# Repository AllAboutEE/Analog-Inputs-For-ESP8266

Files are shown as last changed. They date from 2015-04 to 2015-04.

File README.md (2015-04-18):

# MCP3021 Array Breakout Board
A breakout board for four (4) I2C 10-bit analog to digital (A/D) converters. 

## Where to Buy

## What is it?
A board with four analog to digital (A/D) converters that your ESP8266 can interface with it using I2C.

## Why did you make it?
The ESP8266 is great module, but it lacks some functionality that it's often necessary to use another microcontroller to accomplish what you want. One of the features that it lacks are A/D converters (it only has one and it's hard to access if you have the ESP-01 version).

## Hardware

### Technical Details

- 4 Microchip MCP3021 A/D converters
- I2C interface
- 10-bit resolution
- Single supply specified operation: 2.7V to 5.5V

[MCP3021 A/D converter datasheet](http://ww1.microchip.com/downloads/en/DeviceDoc/21805B.pdf)

## Software

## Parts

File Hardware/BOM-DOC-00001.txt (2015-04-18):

Partlist exported from C:/Users/Miguel/Documents/eagle/MCP3021A-Array-Breakout/Hardware/DOC-00001.sch at 3/19/2015 11:53:24 AM

Part Value            Device         Package     Description                MPN              PRICE STORE              
C1   0.1uF            C-USC0805K     C0805K      CAPACITOR, American symbol VJ0805Y104MXXAC  0.06  mouser.com         
JP1  v                PINHD-1X8      1X08        PIN HEADER                 825433-8         0.84  mouser.com         
R1   4.7k             R-US_R0805     R0805       RESISTOR, American symbol  CRCW08054K70FKEA 0.08  mouser.com         
R2   4.7k             R-US_R0805     R0805       RESISTOR, American symbol  CRCW08054K70FKEA 0.08  mouser.com         
U$1  MCP3021A0T-E/OT  MCP3021XX-X/OT SOT-23-5_MC                            MCP3021A0T-E/OT  1.07  microchipdirect.com
U$2  MCP3021A1T-E/OT  MCP3021XX-X/OT SOT-23-5_MC                            MCP3021A1T-E/OT  1.07  microchipdirect.com
U$3  MCP3021A2T-E/OT  MCP3021XX-X/OT SOT-23-5_MC                            MCP3021A2T-E/OT  1.07  microchipdirect.com
U$4  MCP3021A3T-E/OT  MCP3021XX-X/OT SOT-23-5_MC                            MCP3021A3T-E/OT  1.07  microchipdirect.com

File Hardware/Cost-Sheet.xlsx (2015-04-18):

Order Name | Cost (USD) | Comments
PCB | 2.5 | Free shipping
Converters | 46.32 | 40 sensors. Free shipping until march 30 coupon saved ~$6.00
R,C,H | 16.18 | Resistors, Caps, 1x8 Headers. Shipping was 4.99
Total | 65

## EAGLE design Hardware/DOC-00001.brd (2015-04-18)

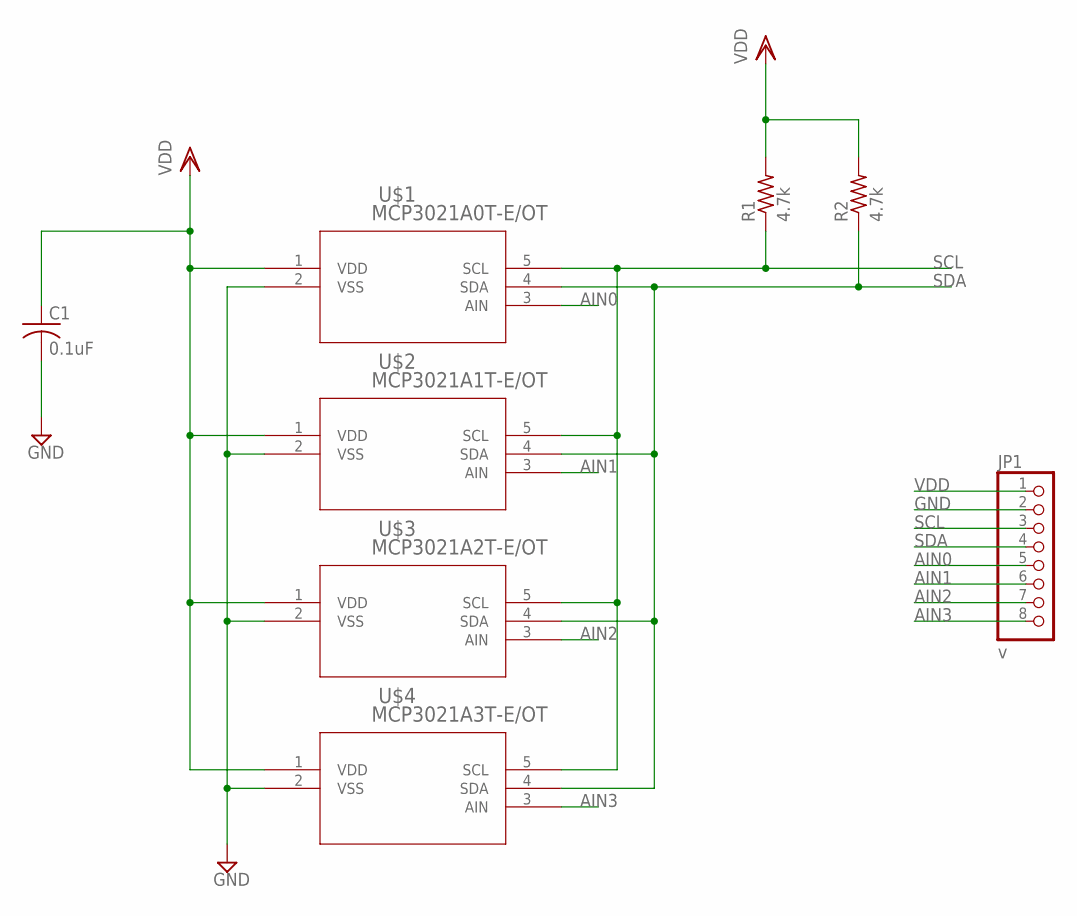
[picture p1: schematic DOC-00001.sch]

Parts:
C1: 0.1uF; C0805K; MPN VJ0805Y104MXXAC
JP1: v; 1X08; MPN 825433-8
R1, R2: 4.7k; R0805; MPN CRCW08054K70FKEA
U$1: MCP3021A0T-E/OT; SOT-23-5_MC; MPN MCP3021A0T-E/OT
U$2: MCP3021A1T-E/OT; SOT-23-5_MC; MPN MCP3021A1T-E/OT
U$3: MCP3021A2T-E/OT; SOT-23-5_MC; MPN MCP3021A2T-E/OT
U$4: MCP3021A3T-E/OT; SOT-23-5_MC; MPN MCP3021A3T-E/OT

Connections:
AIN0: JP1.5, U$1.3 (AIN)
AIN1: JP1.6, U$2.3 (AIN)
AIN2: JP1.7, U$3.3 (AIN)
AIN3: JP1.8, U$4.3 (AIN)
GND: C1.2, JP1.2, U$1.2 (VSS), U$2.2 (VSS), U$3.2 (VSS), U$4.2 (VSS)
SCL: JP1.3, R1.1, U$1.5 (SCL), U$2.5 (SCL), U$3.5 (SCL), U$4.5 (SCL)
SDA: JP1.4, R2.1, U$1.4 (SDA), U$2.4 (SDA), U$3.4 (SDA), U$4.4 (SDA)
VDD: C1.1, JP1.1, R1.2, R2.2, U$1.1 (VDD), U$2.1 (VDD), U$3.1 (VDD), U$4.1 (VDD)

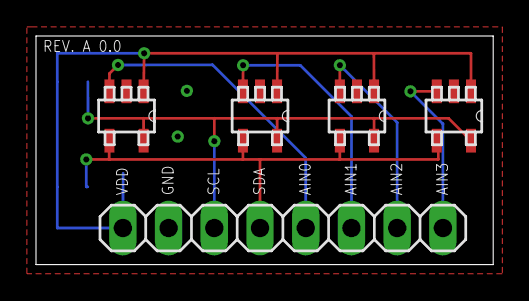
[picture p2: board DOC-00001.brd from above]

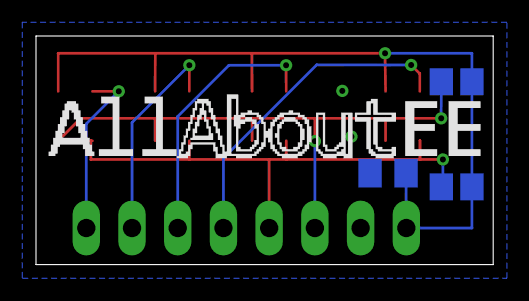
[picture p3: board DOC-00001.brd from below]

Board: 2 copper layers, 25.4 x 12.7 mm, 8 parts (3 on the bottom side), 8 nets.

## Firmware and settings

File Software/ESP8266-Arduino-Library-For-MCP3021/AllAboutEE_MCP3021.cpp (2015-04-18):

#include <AllAboutEE_MCP3021.h>

/**
 * @brief Sets the pin and fixed address bits for I2C
 * 
 * @author Carlos (4/12/2015)
 * 
 * @param sda The SDA pin number
 * @param scl The SCL pin number
 */
void AllAboutEE::MCP3021::begin(int sda, int scl)
{
	Wire.pins(sda,scl);
	Wire.begin(MCP3021_I2C_ADDRESS);
}

/**
 * @brief Gives a conversion's result as a digital value between
 *        0 and 1023
 * 
 * @author Carlos (4/12/2015)
 * 
 * @param deviceId The last three bits in the device's I2C 
 *                 address. This would be the last number in
 *                 device's name e.g. for an MCP3021A5 deviceId
 *                 = 5, for an MCP3021A3 deviceId = 3.
 * 
 * @return uint16_t The 10-bit conversion result, a value from 0
 *         to 1023
 */
uint16_t AllAboutEE::MCP3021::read(int deviceId)
{
    // we'll read the bytes from the I2C bus into this array
    uint8_t data[2];
    data[0] = 0x00;
    data[1] = 0x00;

    // the array is a 10-bit result, the smallest type that can contain it is uint16_t
    uint16_t result = 0x0000;

    // The device's address is binary [1][0][0][1][A0][A1][A2] where [A0][A1][A2] is the device's unique id
    Wire.requestFrom(MCP3021_I2C_ADDRESS|deviceId, 2);

    for(int i =0; Wire.available() > 0;i++)
    {
        data[i] = Wire.read();
    }
    // The converter's 10-bit result is two bytes that looks like this:
    // [0][0][0][0][D9][D8][D7][D6] [D5][D4][D3][D1][D0][x][x]
    // so to put them in one variable ...
    result = (result | data[0]) << 6; // we take the MSB and shift it left 6 times
    data[1] = data[1] >> 2; // we take the LSB and shift it right two times
    result = result | data[1]; // we OR both bytes

    return result;
}

/**
 * @brief Gives a converter's result as an analog value between 
 *        0 and VDD
 * 
 * @author Carlos (4/12/2015)
 * 
 * @param deviceId The last three bits in the device's I2C 
 *                 address. This would be the last number in
 *                 device's name e.g. for an MCP3021A5 deviceId
 *                 = 5, for an MCP3021A3 deviceId = 3.
 *  
 * @param vdd The output of the power supply used to power the 
 *            converter.
 * 
 * @return float The conversion result from 0 to VDD
 */
float AllAboutEE::MCP3021::read(int deviceId, float vdd)
{
	uint16_t result = read(deviceId);
	
	return ((float)result * (vdd / 1023));	
}

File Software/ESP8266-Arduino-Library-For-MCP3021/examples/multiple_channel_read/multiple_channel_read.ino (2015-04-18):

/** 
 *  @details Need more analog pins for your ESP8266? This
 *        example shows how to read and print a digital and
 *        analog value from the MCP3021A0, MCP3021A1, MCP3021A2,
 *        and MCP3021A3 converters.
 *  
 * @link  You can buy an MCP3021 array breakout board from this 
 *        URL: 
 *  
 *  
 * @note Converter datasheet 
 *       http://ww1.microchip.com/downloads/en/DeviceDoc/21805B.pdf
 * 
 */
#include <AllAboutEE_MCP3021.h>
#include <Wire.h>

using namespace AllAboutEE;

MCP3021 mcp3021;


void setup()
{
  mcp3021.begin(0,2);
  Serial.begin(9600);
}

void loop()
{
	Serial.println("New Readings");
		
	for(int i = 0; i < 4; i++) // read analog value from converters MCP3021A0 to MCP3021A3 (that is 4 converters total)
	{
		Serial.print("Channel ");
		Serial.println(i);
		Serial.print("Digital Value: ");
		Serial.println(mcp3021.read(i));

		Serial.print("Analog Value: ");
		Serial.println(mcp3021.read(i,3.3));
		Serial.println();
		delay(500);
	}
	  
}

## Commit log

2015-03-19 First commit. Added schematic and board files.
    [DOC-00001.brd, DOC-00001.sch]
2015-03-19 Routed. Needs ground layers.
    [DOC-00001.brd, DOC-00001.sch]
2015-03-19 Added BOM.
2015-03-19 Added HTML extension to BOM.
2015-03-19 Added txt version of BOM.
2015-03-19 Changed the PCB layout
    [DOC-00001.brd]
2015-03-20 Fixed values of Ux in sch to match PCBs, there was a space after the value name so I just deleted that. Added cost sheet.
    [Cost-Sheet.xlsx, DOC-00001.sch]
2015-04-13 Fixed I2C address in library and added for loop
    [AllAboutEE_MCP3021.cpp]
2015-04-18 Completed version. This was uploaded to OSHPARK
    [Cost-Sheet.xlsx, DOC-00001.brd, DOC-00001.sch]
2015-04-18 Deleted brd and sch because merging was a mess so I'll just put the files that were uploaded to OSH park in the next commit.
    [DOC-00001.brd, DOC-00001.sch]
2015-04-18 Re added files that were deleted.
    [DOC-00001.brd, DOC-00001.sch]
2015-04-18 Added Arduino library.
2015-04-18 Renamed arduino library folder.
2015-04-18 Added NodeMcu library Renamed Arduino library
